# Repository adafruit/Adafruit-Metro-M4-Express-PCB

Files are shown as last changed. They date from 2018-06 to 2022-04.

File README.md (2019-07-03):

## Adafruit Metro M4 Express PCB

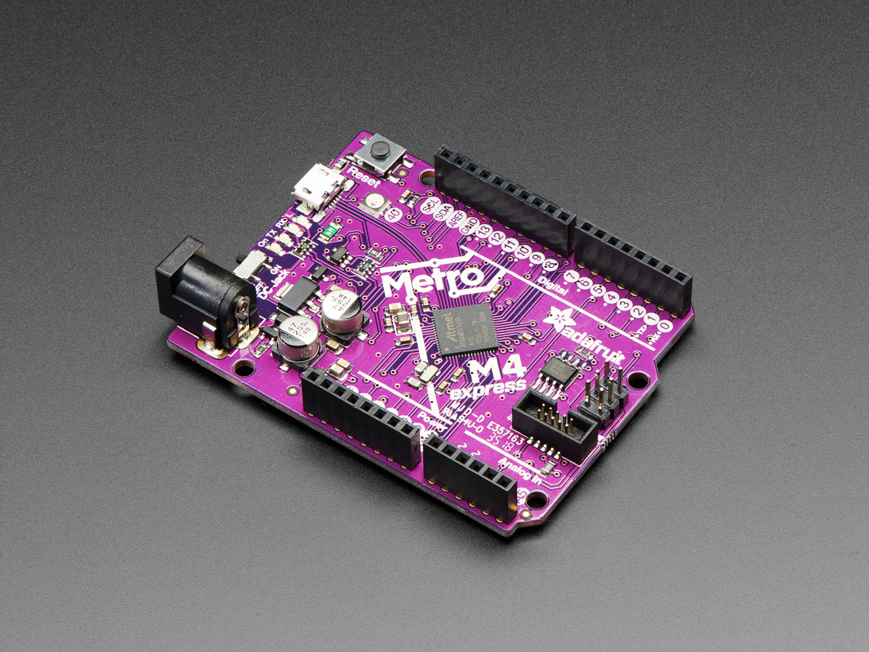
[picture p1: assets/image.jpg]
<a href="http://www.adafruit.com/products/3382"><br/>
Click here to purchase one from the Adafruit shop</a>

PCB files for the Adafruit Metro Express M4. PCB format is EagleCAD schematic and board layout

For more details, check out the product pages at
* https://www.adafruit.com/products/3382

### Description

Are you ready? Really ready? Cause here comes the fastest, most powerful Metro ever. The Adafruit Metro M4 featuring the Microchip ATSAMD51. This Metro is like a bullet train, with it's 120MHz Cortex M4 with floating point support. Your code will zig and zag and zoom, and with a bunch of extra peripherals for support, this will for sure be your favorite new chipset.

To start off our ATSAMD51 journey we decided to kick it off with the classic 'Arduino compatible' shape and pinout you know and love. This Metro is the same size as the others, and is compatible with all our shields. It's got analog pins where you expect, and SPI/UART/I2C hardware support in the same spot as the Metro 328 and M0. But! It's powered with an ATSAMD51J19.

### License

Adafruit invests time and resources providing this open source design, please support Adafruit and open-source hardware by purchasing products from [Adafruit](https://www.adafruit.com)!

Designed by Limor Fried/Ladyada for Adafruit Industries.

Creative Commons Attribution/Share-Alike, all text above must be included in any redistribution. See license.txt for additional details.

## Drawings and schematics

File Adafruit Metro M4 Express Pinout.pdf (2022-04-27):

# Adafruit Metro M4 Express

# https://www.adafruit.com/product/3382

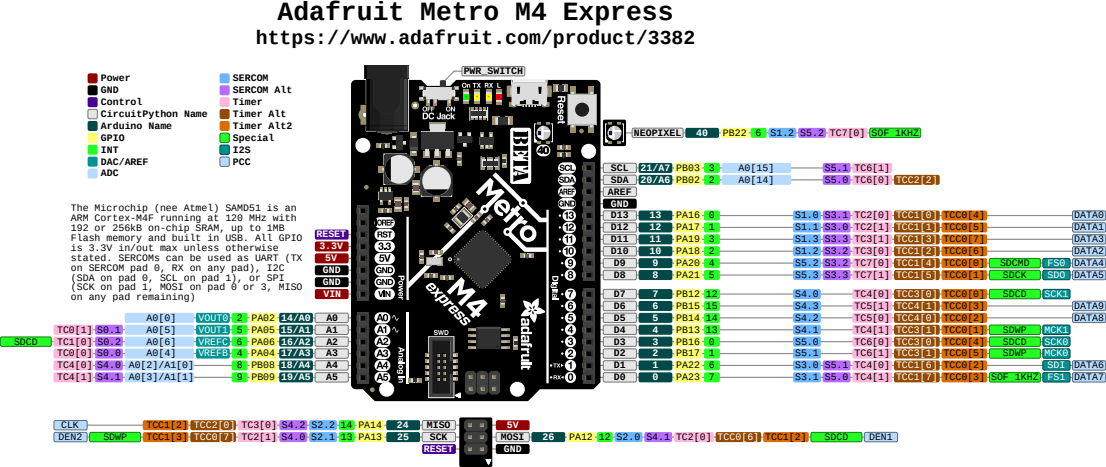
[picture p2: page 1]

The Microchip (nee Atmel) SAMD51 is an
ARM Cortex-M4F running at 120 MHz with
192 or 256kB on-chip SRAM, up to 1MB
Flash memory and built in USB. All GPIO
is 3.3V in/out max unless otherwise
stated. SERCOMs can be used as UART (TX
on SERCOM pad 0, RX on any pad), I2C
(SDA on pad 0, SCL on pad 1), or SPI
(SCK on pad 1, MOSI on pad 0 or 3, MISO
on any pad remaining)

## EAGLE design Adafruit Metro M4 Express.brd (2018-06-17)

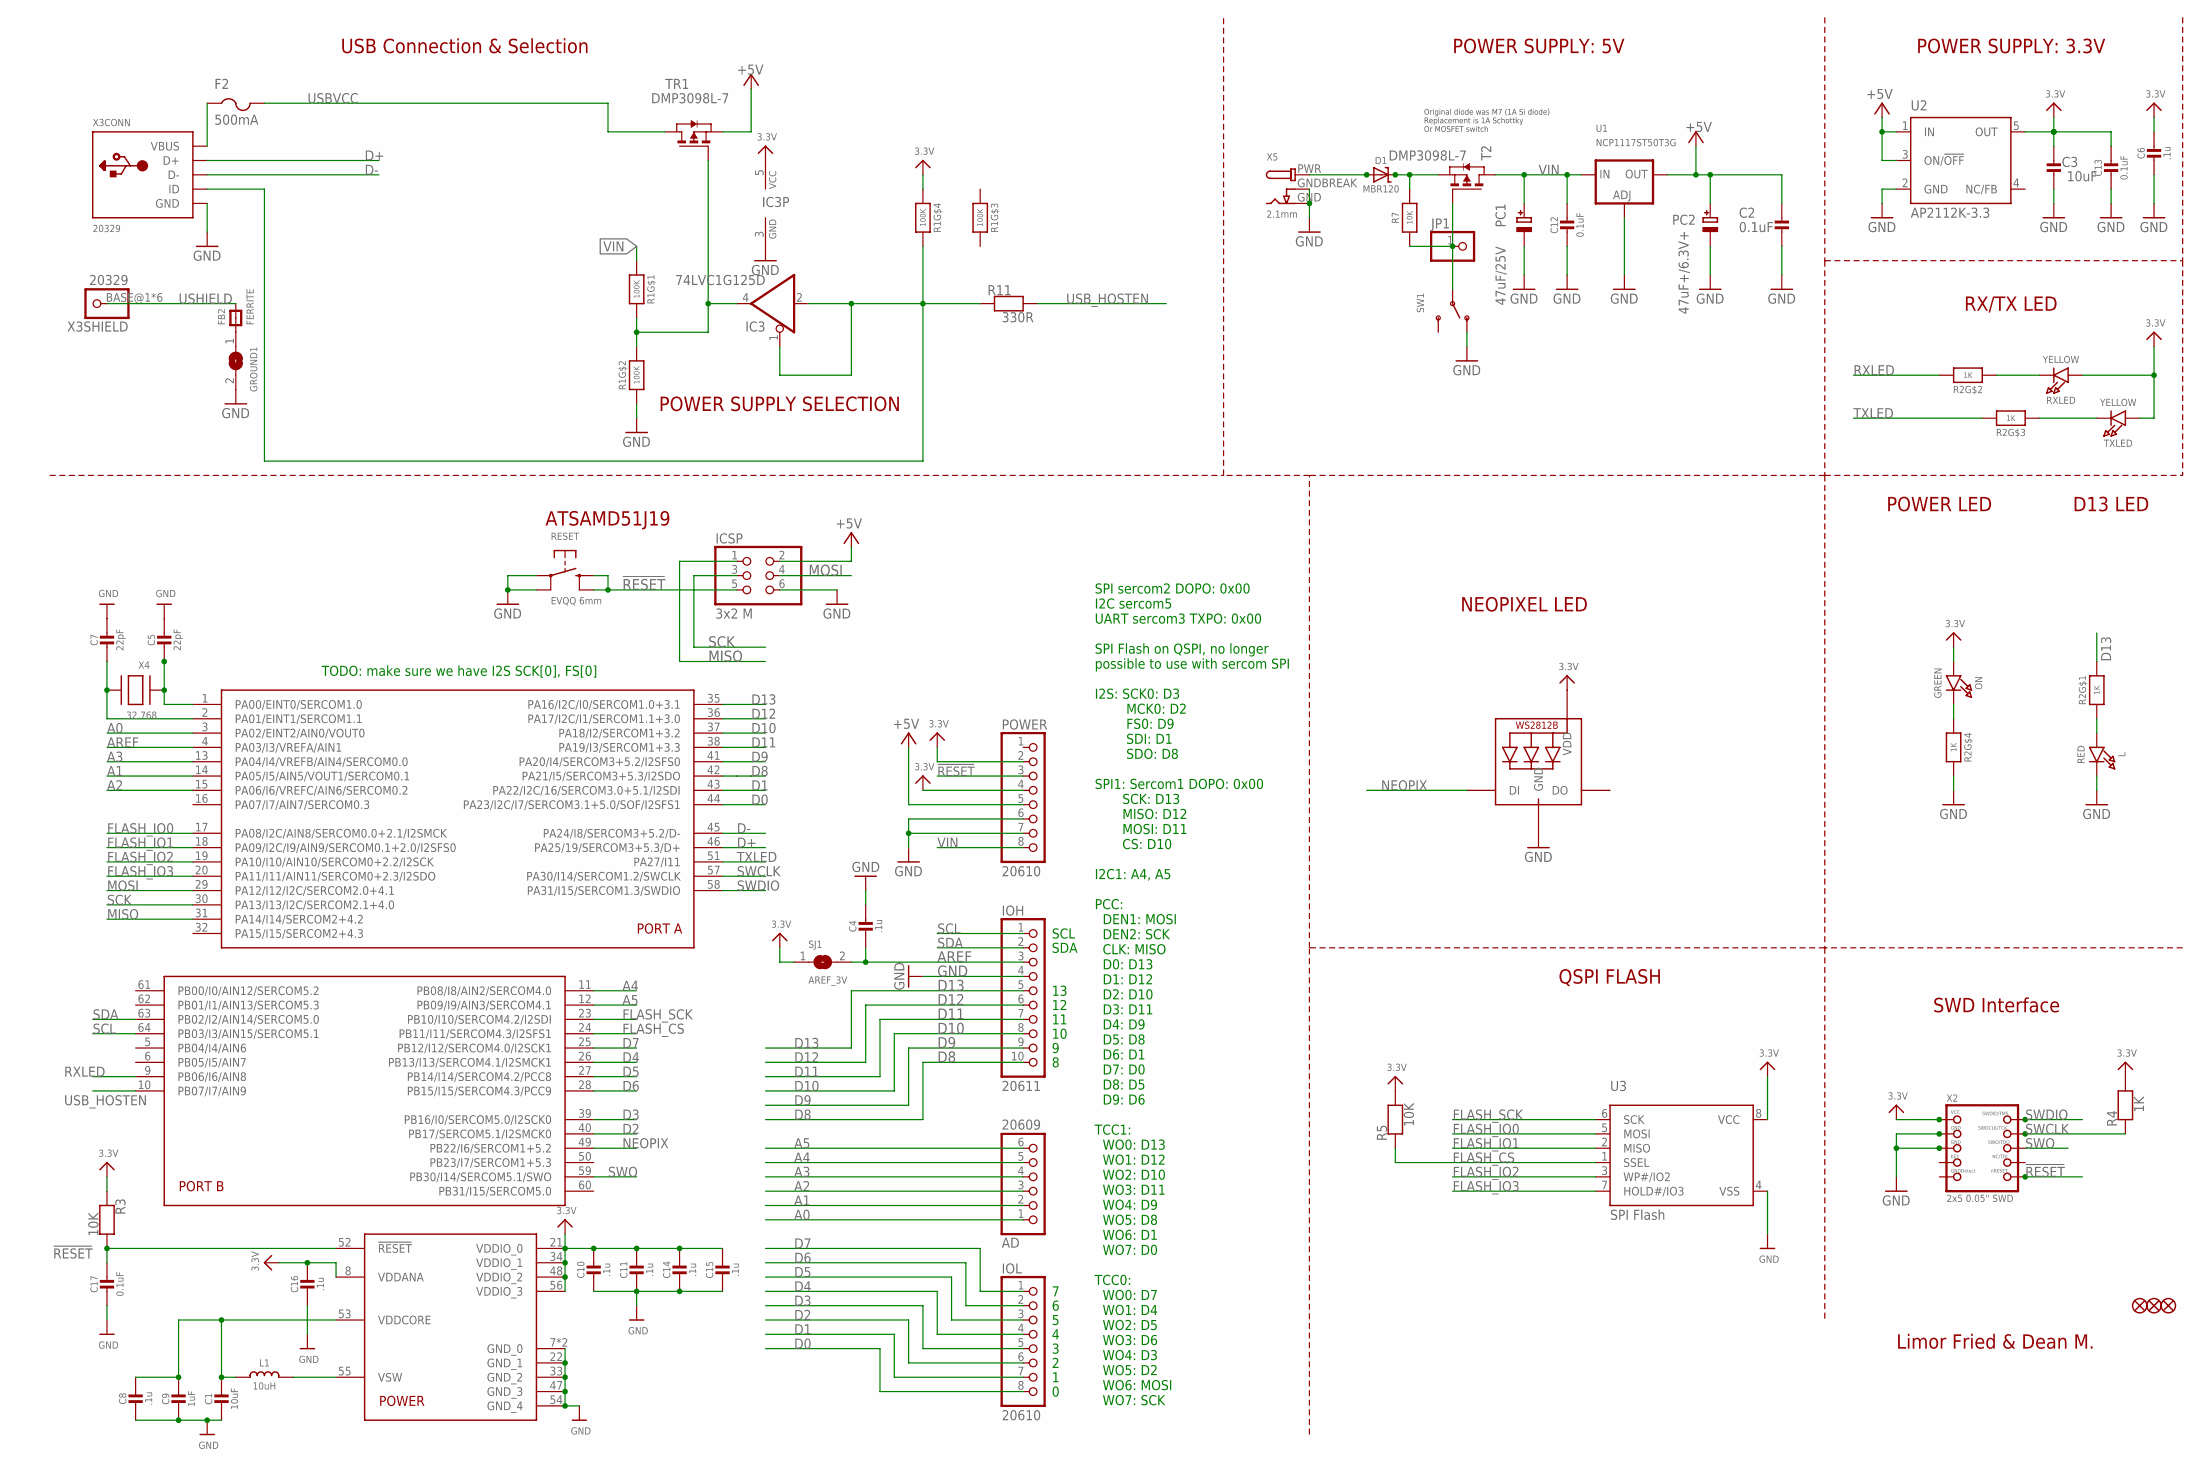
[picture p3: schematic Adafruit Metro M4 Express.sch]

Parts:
AD: 20609; 1X06_OVALWAVE
C1, C3: 10uF; 0805-NO
C2: 0.1uF; 0805-NO
C4, C6, C8, C10, C11, C14, C15, C16: .1u; 0603-NO
C5, C7: 22pF; 0603-NO
C9: 1uF; 0603-NO
C12, C13, C17: 0.1uF; 0603-NO
D1: MBR120; SOD-123
F2: 500mA; R1206
FB2: FERRITE; 0805-NO
FD1, FD2, FD3: FIDUCIAL_1MM
GROUND1: SOLDERJUMPERCLOSED; SOLDERJUMPER_CLOSEDWIRE
IC3: 74LVC1G125D; SOT23-5
ICSP: 3x2 M; 2X03_ROUND_70MIL
IOH: 20611; 1X10_OVALWAVE
IOL: 20610; 1X08_OVALWAVE
JP1: HEADER-1X1ROUND; 1X01_ROUND
L: RED; CHIPLED_0805_NOOUTLINE
L1: 10uH; INDUCTOR_1007
LED1: WS2812B3535; LED3535
ON: GREEN; CHIPLED_0805_NOOUTLINE
PC1: 47uF/25V; PANASONIC_D
PC2: 47uF+/6.3V+; PANASONIC_D
POWER: 20610; 1X08_OVALWAVE
R1: 100K; RESPACK_4X0603
R2: 1K; RESPACK_4X0603
R3, R5, R7: 10K; 0603-NO
R4: 1K; 0603-NO
R11: 330R; 0603-NO
RESET: EVQQ 6mm; EVQ-Q2
RXLED: YELLOW; CHIPLED_0805_NOOUTLINE
SJ1: AREF_3V; SOLDERJUMPER_CLOSEDWIRE
SW1: SWITCH_SPDT; SPDT_SMT_SSSS811101
T2: DMP3098L-7; SOT-23
TR1: DMP3098L-7; SOT-23
TXLED: YELLOW; CHIPLED_0805_NOOUTLINE
U1: NCP1117ST50T3G; SOT223-R
U2: AP2112K-3.3; SOT23-DBV
U3: SPI Flash; SOIC8_208MIL
U$1: ATSAMD51J; PQFN64-1
X2: 2x5 0.05" SWD; 2X05_1.27MM_BOX_POSTS
X3: 20329; 4UCONN_20329_V2
X4: 32.768; XTAL3215
X5: 2.1mm; DCJACK_2MM_PTH

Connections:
3.3V: C3.2, C6.2, C10.2, C11.2, C13.1, C14.2, C15.2, C16.2, IC3.5 (VCC), LED1.2 (VDD), ON.A, POWER.2, POWER.4, R1.4 (1), R3.1, R4.2, R5.2, RXLED.A, SJ1.1, TXLED.A, U2.5 (OUT), U3.8 (VCC), U$1.8 (VDDANA), U$1.21 (VDDIO_0), U$1.34 (VDDIO_1), U$1.48 (VDDIO_2), U$1.56 (VDDIO_3), X2.1 (VCC)
!RESET: C17.2, ICSP.5, POWER.3, R3.2, RESET.B (S), RESET.B' (S1), U$1.52 (!RESET), X2.10 (NRESET)
+5V: C2.2, ICSP.2, PC2.+, POWER.5, TR1.2 (S), U1.2 (OUT), U1.4 (OUT), U2.1 (IN), U2.3 (ON/!OFF)
A0: AD.1, U$1.3 (PA02/EINT2/AIN0/VOUT0)
A1: AD.2, U$1.14 (PA05/I5/AIN5/VOUT1/SERCOM0.1)
A2: AD.3, U$1.15 (PA06/I6/VREFC/AIN6/SERCOM0.2)
A3: AD.4, U$1.13 (PA04/I4/VREFB/AIN4/SERCOM0.0)
A4: AD.5, U$1.11 (PB08/I8/AIN2/SERCOM4.0)
A5: AD.6, U$1.12 (PB09/I9/AIN3/SERCOM4.1)
AREF: C4.1, IOH.3, SJ1.2, U$1.4 (PA03/I3/VREFA/AIN1)
D0: IOL.8, U$1.44 (PA23/I2C/I7/SERCOM3.1+5.0/SOF/I2SFS1)
D1: IOL.7, U$1.43 (PA22/I2C/16/SERCOM3.0+5.1/I2SDI)
D2: IOL.6, U$1.40 (PB17/SERCOM5.1/I2SMCK0)
D3: IOL.5, U$1.39 (PB16/I0/SERCOM5.0/I2SCK0)
D4: IOL.4, U$1.26 (PB13/I13/SERCOM4.1/I2SMCK1)
D5: IOL.3, U$1.27 (PB14/I14/SERCOM4.2/PCC8)
D6: IOL.2, U$1.28 (PB15/I15/SERCOM4.3/PCC9)
D7: IOL.1, U$1.25 (PB12/I12/SERCOM4.0/I2SCK1)
D8: IOH.10, U$1.42 (PA21/I5/SERCOM3+5.3/I2SDO)
D9: IOH.9, U$1.41 (PA20/I4/SERCOM3+5.2/I2SFS0)
D10: IOH.8, U$1.37 (PA18/I2/SERCOM1+3.2)
D11: IOH.7, U$1.38 (PA19/I3/SERCOM1+3.3)
D12: IOH.6, U$1.36 (PA17/I2C/I1/SERCOM1.1+3.0)
D13: IOH.5, R2.8 (2), U$1.35 (PA16/I2C/I0/SERCOM1.0+3.1)
D+: U$1.46 (PA25/19/SERCOM3+5.3/D+), X3.D+
D-: U$1.45 (PA24/I8/SERCOM3+5.2/D-), X3.D-
FLASH_CS: R5.1, U3.1 (SSEL), U$1.24 (PB11/I11/SERCOM4.3/I2SFS1)
FLASH_IO0: U3.5 (MOSI), U$1.17 (PA08/I2C/AIN8/SERCOM0.0+2.1/I2SMCK)
FLASH_IO1: U3.2 (MISO), U$1.18 (PA09/I2C/I9/AIN9/SERCOM0.1+2.0/I2SFS0)
FLASH_IO2: U3.3 (WP#/IO2), U$1.19 (PA10/I10/AIN10/SERCOM0+2.2/I2SCK)
FLASH_IO3: U3.7 (HOLD#/IO3), U$1.20 (PA11/I11/AIN11/SERCOM0+2.3/I2SDO)
FLASH_SCK: U3.6 (SCK), U$1.23 (PB10/I10/SERCOM4.2/I2SDI)
GND: C1.2, C2.1, C3.1, C4.2, C5.2, C6.1, C7.2, C8.1, C9.2, C10.1, C11.1, C12.2, C13.2, C14.1, C15.1, C16.1, C17.1, GROUND1.2, IC3.3 (GND), ICSP.6, IOH.4, L.C, LED1.4 (GND), PC1.-, PC2.-, POWER.6, POWER.7, R1.2 (1), R2.5 (2), RESET.A, RESET.A' (P1), SW1.A (O), U1.1 (ADJ), U2.2 (GND), U3.4 (VSS), U$1.7 (GND_0), U$1.22 (GND_1), U$1.33 (GND_2), U$1.47 (GND_3), U$1.54 (GND_4), U$1.EXP (GND_0), X2.3 (GND), X2.5 (GND), X3.GND, X5.GND, X5.GNDBREAK
MISO: ICSP.1, U$1.31 (PA14/I14/SERCOM2+4.2)
MOSI: ICSP.4, U$1.29 (PA12/I12/I2C/SERCOM2.0+4.1)
unnamed: L.A, R2.1
unnamed: FB2.1, GROUND1.1
unnamed: ON.C, R2.4 (1)
unnamed: L1.P$2 (2), U$1.55 (VSW)
unnamed: R2.2 (1), RXLED.C
unnamed: R2.3 (1), TXLED.C
unnamed: C5.1, U$1.1 (PA00/EINT0/SERCOM1.0), X4.P$1
unnamed: IC3.1 (OE), IC3.2 (I), R1.5 (2), R11.1, X3.ID
unnamed: IC3.4 (O), R1.7 (2), R1.8 (2), TR1.3 (G)
unnamed: C7.1, U$1.2 (PA01/EINT1/SERCOM1.1), X4.P$2
unnamed: D1.C, R7.2, T2.2 (S)
NEOPIX: LED1.1 (DI), U$1.49 (PB22/I6/SERCOM1+5.2)
PWRIN: D1.A, X5.PWR
PWR_SWITCH: JP1.1, R7.1, SW1.B, T2.3 (G)
RXLED: R2.7 (2), U$1.9 (PB06/I6/AIN8)
SCK: ICSP.3, U$1.30 (PA13/I13/I2C/SERCOM2.1+4.0)
SCL: IOH.1, U$1.64 (PB03/I3/AIN15/SERCOM5.1)
SDA: IOH.2, U$1.63 (PB02/I2/AIN14/SERCOM5.0)
SWCLK: R4.1, U$1.57 (PA30/I14/SERCOM1.2/SWCLK), X2.4 (SWDCLK)
SWDIO: U$1.58 (PA31/I15/SERCOM1.3/SWDIO), X2.2 (SWDIO)
SWO: U$1.59 (PB30/I14/SERCOM5.1/SWO), X2.6 (SWO)
TXLED: R2.6 (2), U$1.51 (PA27/I11)
USBVCC: F2.2, TR1.1 (D)
USB_HOSTEN: R11.2, U$1.10 (PB07/I7/AIN9)
USHIELD: FB2.2, X3.BASE@1 (1), X3.BASE@2 (1), X3.SPRT@1 (1), X3.SPRT@2 (1), X3.SPRT@3 (1), X3.SPRT@4 (1)
VBUS: F2.1, X3.VBUS
VDDCORE: C1.1, C8.2, C9.1, L1.P$1 (1), U$1.53 (VDDCORE)
VIN: C12.1, PC1.+, POWER.8, R1.1, T2.1 (D), U1.3 (IN)

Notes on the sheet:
SDA
SCL
Limor Fried & Dean M.
Original diode was M7 (1A Si diode) Replacement is 1A Schottky Or MOSFET switch
POWER SUPPLY: 5V
USB Connection & Selection
POWER SUPPLY: 3.3V
POWER LED
ATSAMD51J19
POWER SUPPLY SELECTION
D13 LED
RX/TX LED
NEOPIXEL LED
QSPI FLASH
SWD Interface
SPI sercom2 DOPO: 0x00 I2C sercom5 UART sercom3 TXPO: 0x00 SPI Flash on QSPI, no longer possible to use with sercom SPI I2S: SCK0: D3 MCK0: D2 FS0: D9 SDI: D1 SDO: D8 SPI1: Sercom1 DOPO: 0x00 SCK: D13 MISO: D12 MOSI: D11 CS: D10 I2C1: A4, A5 PCC: DEN1: MOSI DEN2: SCK CLK: MISO D0: D13 D1: D12 D2: D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
TODO: make sure we have I2S SCK[0], FS[0]

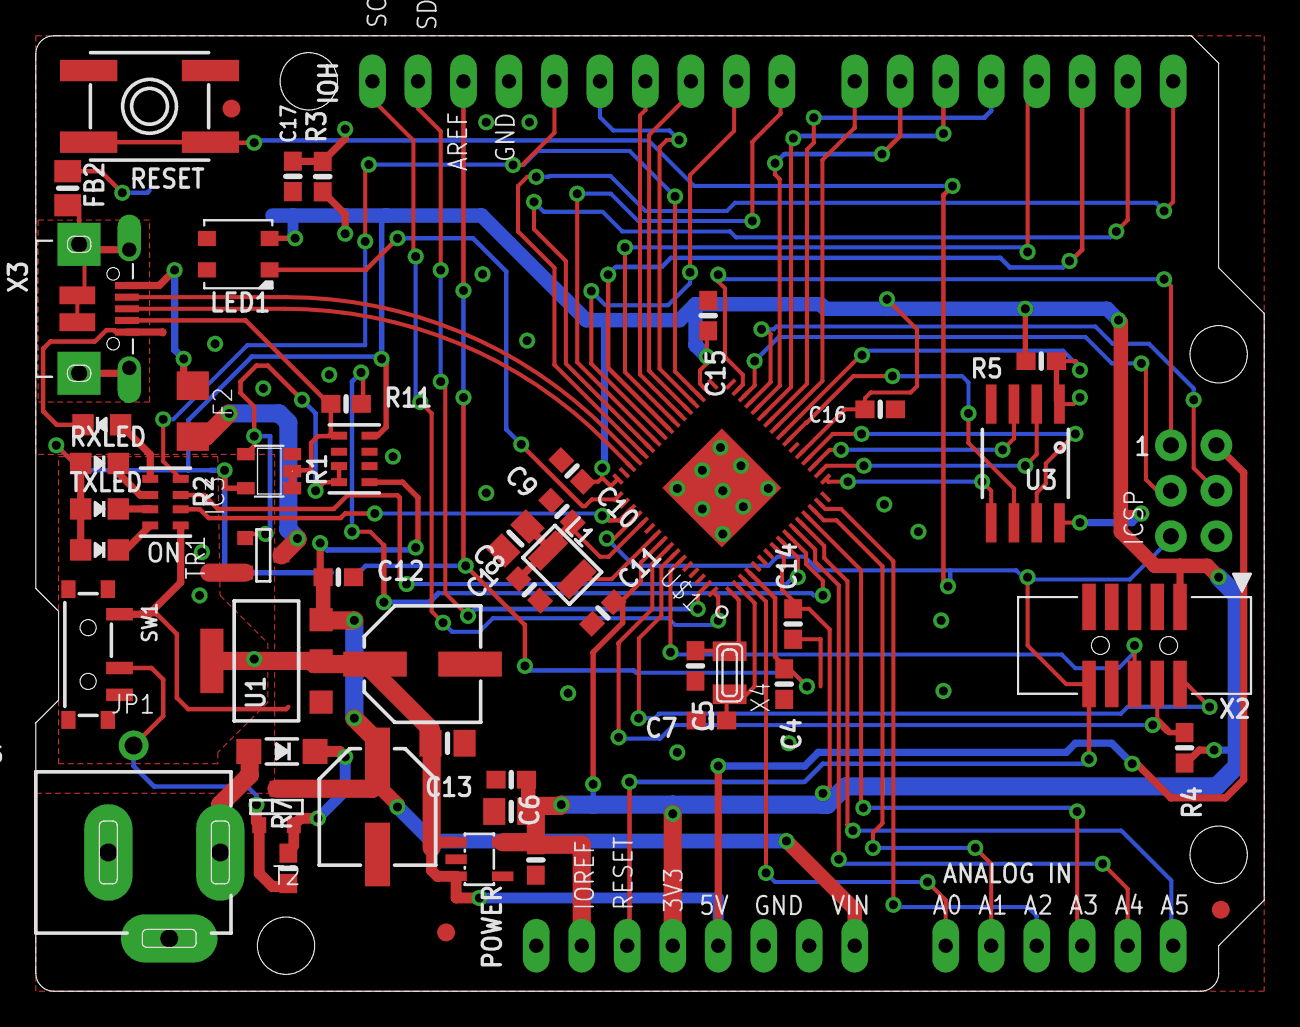
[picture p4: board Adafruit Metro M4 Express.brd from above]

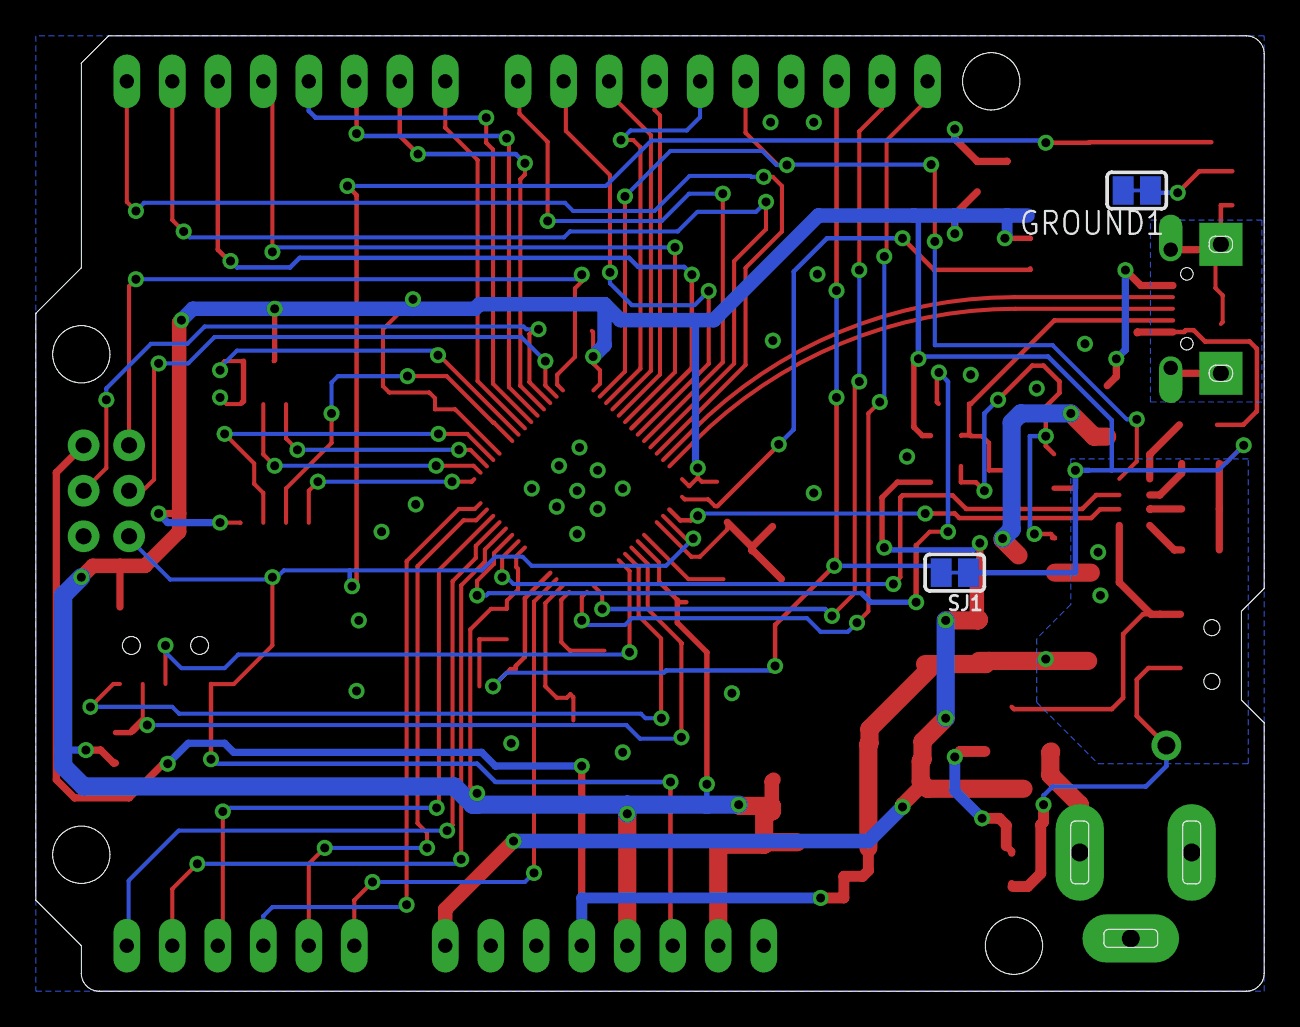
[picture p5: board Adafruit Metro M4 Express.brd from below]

Board: 2 copper layers, 68.6 x 53.3 mm, 61 parts (3 on the bottom side), 63 nets.

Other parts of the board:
U$23: METROM4_REVF_TOP
U$27: METROM4_REVF_BOT

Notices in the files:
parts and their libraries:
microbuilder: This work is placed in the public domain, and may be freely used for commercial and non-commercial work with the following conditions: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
